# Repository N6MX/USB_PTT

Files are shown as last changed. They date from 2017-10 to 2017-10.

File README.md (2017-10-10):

#======================================================================================
#======================================================================================
# USB_PTT
# This is the design for a USB Push-To-Talk interface for amateur radio.
# This design was intended with work with the Yaesu FT-8900R, but will also work on radios with a similar interface.
#
# Author: Dylon Mutz, KK6OTK
# Email : dylon.mutz@gmail.com
#
# 10/7/2017 -- Initial release
#======================================================================================
#======================================================================================

99-usb_ptt.rules
   A udev rule is needed to set the device file to the dialout group with read/write permissions.
   Add this rules file to /etc/udev/rules.d/

ptt_driver/ptt_driver.ko
   This is the Linux kernel module (or driver) that is compiled from ptt_driver.c. This is the system-level middleman between the userspace application and the actual USB device hardware.
   The module can be loaded manually running the command "insmod <path to ptt_driver.ko"
   To allow the module to load automatically when the system is booted, follow the next steps:
      1) Make a new module directory in the kernel module folder
            "mkdir /lib/modules/`uname -r`/kernel/driver/ptt_driver"
      2) Allow the modprobe command to find the module by placing it under the "/lib/modules/`uname -r`" directory
            "cp usb_ptt/ptt_driver.ko /lib/modules/`uname -r`/kernel/driver/ptt_driver/"
      3) Regenerate module dependencies
            "depmod -ae
      4) Allow module to automatically load by placing a module config file in the "/etc/modules-load.d" directory
            "cp ptt_driver.conf /etc/modules-load.d/"

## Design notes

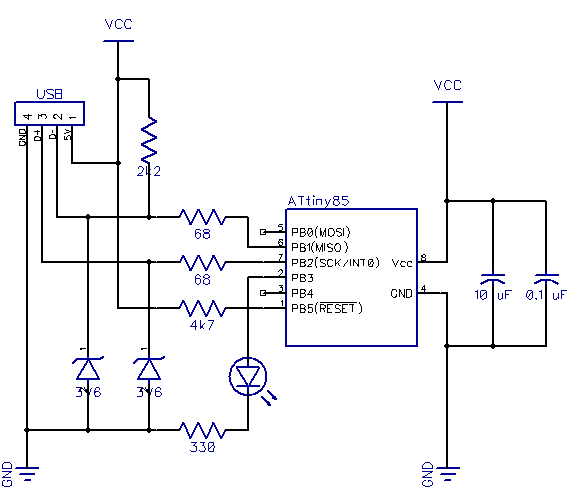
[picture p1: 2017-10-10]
usb_tiny85/schematic.png

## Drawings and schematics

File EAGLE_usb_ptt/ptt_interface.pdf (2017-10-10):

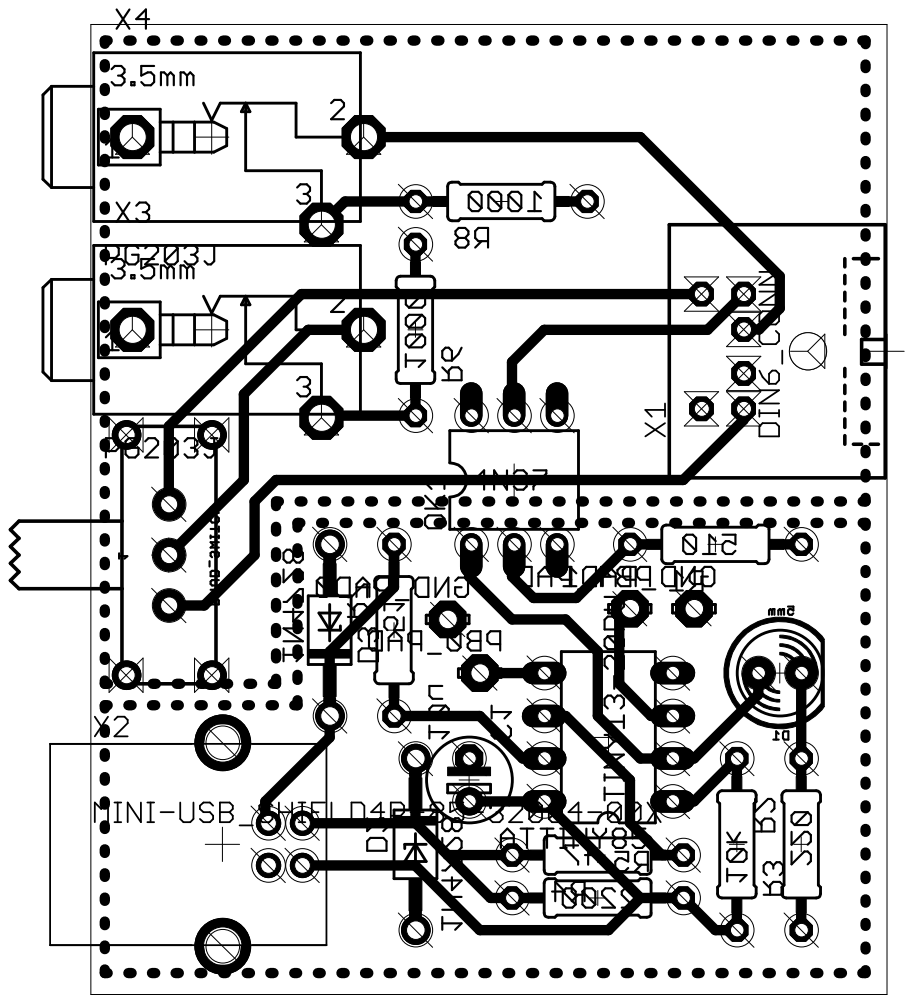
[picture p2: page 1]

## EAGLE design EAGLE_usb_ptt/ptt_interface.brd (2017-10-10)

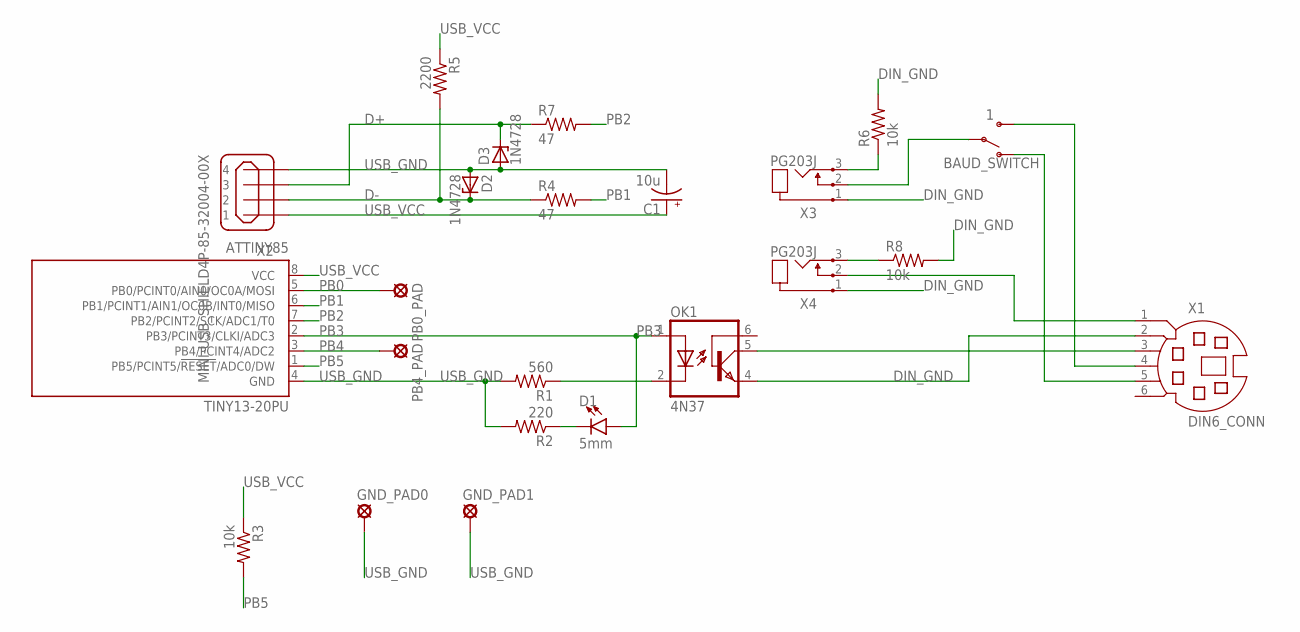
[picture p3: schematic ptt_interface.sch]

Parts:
ATTINY85: TINY13-20PU; DIL08
BAUD_SWITCH: 1; SWITCH_SPDT_PTH_15X5.6MM
C1: 10u; E2,5-5
D1: 5mm; LED_5MM
D2, D3: 1N4728; DO41Z10
GND_PAD0, GND_PAD1: LSP11
OK1: 4N37; DIL06
PB0_PAD, PB4_PAD: LSP11
R1: 560; 0207/10
R2: 220; 0207/10
R3, R6, R8: 10k; 0207/10
R4, R7: 47; 0207/10
R5: 2200; 0207/10
X1: DIN6_CONN; MDIN06SS
X2: MINI-USB_SHIELD4P-85-32004-00X; 85-32004-00X
X3, X4: PG203J

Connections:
D+: D3.C, R7.1, X2.3
D-: D2.C, R4.1, R5.2, X2.2
DIN_GND: OK1.4 (EMI), R6.2, R8.2, X1.2, X3.1, X4.1
unnamed: OK1.2 (C), R1.1
unnamed: D1.K (C), R2.1
unnamed: OK1.5 (COL), X1.3
unnamed: BAUD_SWITCH.2, X3.2 (3)
unnamed: R6.1, X3.3 (2)
unnamed: R8.1, X4.3 (2)
unnamed: BAUD_SWITCH.3 (S), X1.4
unnamed: BAUD_SWITCH.1 (O), X1.5
unnamed: X1.1, X4.2 (3)
PB0: ATTINY85.5 (PB0/PCINT0/AIN0/OC0A/MOSI), PB0_PAD.MP
PB1: ATTINY85.6 (PB1/PCINT1/AIN1/OC0B/INT0/MISO), R4.2
PB2: ATTINY85.7 (PB2/PCINT2/SCK/ADC1/T0), R7.2
PB3: ATTINY85.2 (PB3/PCINT3/CLKI/ADC3), D1.A, OK1.1 (A)
PB4: ATTINY85.3 (PB4/PCINT4/ADC2), PB4_PAD.MP
PB5: ATTINY85.1 (PB5/PCINT5/!RESET!/ADC0/DW), R3.2
USB_GND: ATTINY85.4 (GND), C1.-, D2.A, D3.A, GND_PAD0.MP, GND_PAD1.MP, R1.2, R2.2, X2.4
USB_VCC: ATTINY85.8 (VCC), C1.+, R3.1, R5.1, X2.1

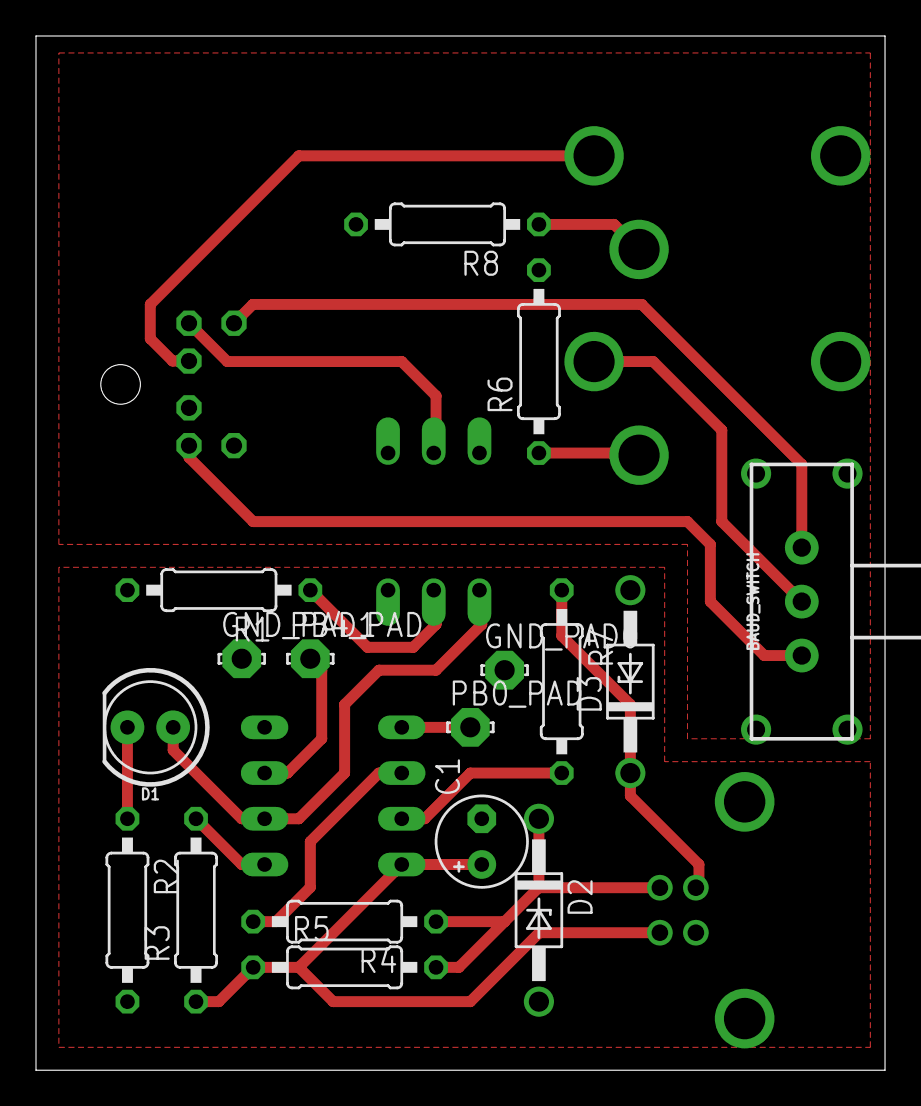
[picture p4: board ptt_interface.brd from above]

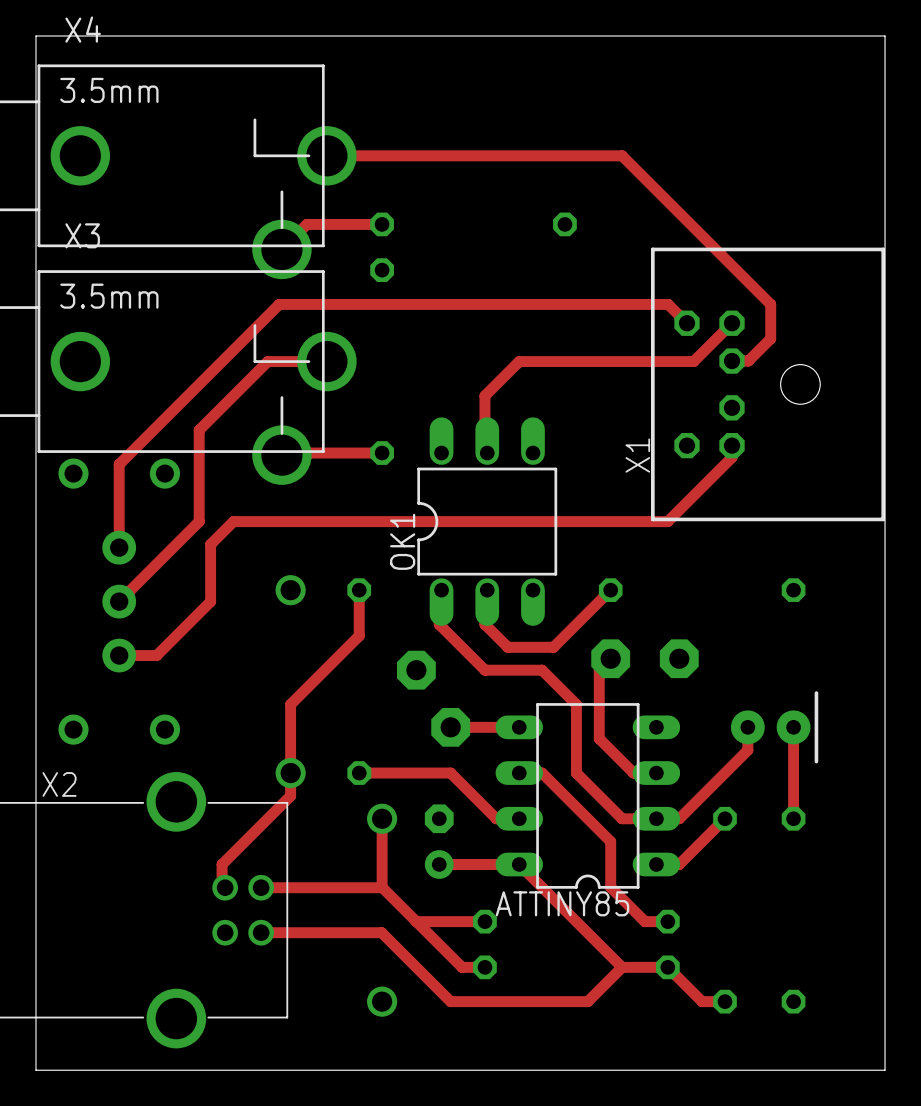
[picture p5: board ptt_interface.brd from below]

Board: 2 copper layers, 47.2 x 57.5 mm, 23 parts (6 on the bottom side), 20 nets.

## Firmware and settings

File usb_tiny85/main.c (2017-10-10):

/**
 * Project: AVR ATtiny USB Tutorial at http://codeandlife.com/
 * Author: Joonas Pihlajamaa, joonas.pihlajamaa@iki.fi
 * Inspired by V-USB example code by Christian Starkjohann
 * Copyright: (C) 2012 by Joonas Pihlajamaa
 * License: GNU GPL v3 (see License.txt)
 */
#include <avr/io.h>
#include <avr/interrupt.h>
#include <avr/wdt.h>
#include <util/delay.h>

#include "usbdrv.h"

//Function declarations
USB_PUBLIC uchar usbFunctionSetup(uchar data[8]);
void hadUsbReset();

#define USB_LED_OFF 0x00
#define USB_LED_ON 0x01
#define LED_PIN (1<<PB3)

//Main program
int main() {
	uchar i;

	DDRB = LED_PIN;					//Setup LED pin as output
	
    wdt_enable(WDTO_1S);			//Enable 1s watchdog timer

    usbInit();						//Initialize V-USB library

	//Enforce re-enumeration
	//Watchdog automatically resets chip after 1 second if freeze occurs
    usbDeviceDisconnect();
    for(i = 0; i<250; i++) {		//Wait 500 ms
        wdt_reset();				//Keep the watchdog happy
        _delay_ms(2);
    }
    usbDeviceConnect();
	
    sei();							//Enable interrupts after re-enumeration
	
    while(1) {
        wdt_reset();				//Keep the watchdog happy
        usbPoll();
    }
	
    return 0;
}


/************************************************************
********************SUPPORTING FUNCTIONS*********************
************************************************************/

// this gets called when custom control message is received
USB_PUBLIC uchar usbFunctionSetup(uchar data[8]) {
	usbRequest_t *rq = (void *)data; // cast data to correct type
	
	switch(rq->bRequest) { // custom command is in the bRequest field
    case USB_LED_ON:
		PORTB |= LED_PIN; // turn LED on
		return 0;
	case USB_LED_OFF: 
		PORTB &= ~LED_PIN; // turn LED off
		return 0;
    }

    return 1; // should not get here
}

#define abs(x) ((x) > 0 ? (x) : (-x))

// Called by V-USB after device reset
void hadUsbReset() {
    int frameLength, targetLength = (unsigned)(1499 * (double)F_CPU / 10.5e6 + 0.5);
    int bestDeviation = 9999;
    uchar trialCal, bestCal, step, region = 0;
    bestCal = 0;

    // do a binary search in regions 0-127 and 128-255 to get optimum OSCCAL
    for(region = 0; region <= 1; region++) {
        frameLength = 0;
        trialCal = (region == 0) ? 0 : 128;
        
        for(step = 64; step > 0; step >>= 1) { 
            if(frameLength < targetLength) // true for initial iteration
                trialCal += step; // frequency too low
            else
                trialCal -= step; // frequency too high
                
            OSCCAL = trialCal;
            frameLength = usbMeasureFrameLength();
            
            if(abs(frameLength-targetLength) < bestDeviation) {
                bestCal = trialCal; // new optimum found
                bestDeviation = abs(frameLength -targetLength);
            }
        }
    }

    OSCCAL = bestCal;
}

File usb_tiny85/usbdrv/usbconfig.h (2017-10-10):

/* Name: usbconfig.h
 * Project: V-USB, virtual USB port for Atmel's(r) AVR(r) microcontrollers
 * Author: Christian Starkjohann
 * Creation Date: 2005-04-01
 * Tabsize: 4
 * Copyright: (c) 2005 by OBJECTIVE DEVELOPMENT Software GmbH
 * License: GNU GPL v2 (see License.txt), GNU GPL v3 or proprietary (CommercialLicense.txt)
 * This Revision: $Id$
 */

#ifndef __usbconfig_h_included__
#define __usbconfig_h_included__

/*
General Description:
This file is an example configuration (with inline documentation) for the USB
driver. It configures V-USB for USB D+ connected to Port D bit 2 (which is
also hardware interrupt 0 on many devices) and USB D- to Port D bit 4. You may
wire the lines to any other port, as long as D+ is also wired to INT0 (or any
other hardware interrupt, as long as it is the highest level interrupt, see
section at the end of this file).
*/

/* ---------------------------- Hardware Config ---------------------------- */

#define USB_CFG_IOPORTNAME      B
/* This is the port where the USB bus is connected. When you configure it to
 * "B", the registers PORTB, PINB and DDRB will be used.
 */
#define USB_CFG_DMINUS_BIT      1
/* This is the bit number in USB_CFG_IOPORT where the USB D- line is connected.
 * This may be any bit in the port.
 */
#define USB_CFG_DPLUS_BIT       2
/* This is the bit number in USB_CFG_IOPORT where the USB D+ line is connected.
 * This may be any bit in the port. Please note that D+ must also be connected
 * to interrupt pin INT0! [You can also use other interrupts, see section
 * "Optional MCU Description" below, or you can connect D- to the interrupt, as
 * it is required if you use the USB_COUNT_SOF feature. If you use D- for the
 * interrupt, the USB interrupt will also be triggered at Start-Of-Frame
 * markers every millisecond.]
 */
#define USB_CFG_CLOCK_KHZ       (F_CPU/1000)
/* Clock rate of the AVR in kHz. Legal values are 12000, 12800, 15000, 16000,
 * 16500, 18000 and 20000. The 12.8 MHz and 16.5 MHz versions of the code
 * require no crystal, they tolerate +/- 1% deviation from the nominal
 * frequency. All other rates require a precision of 2000 ppm and thus a
 * crystal!
 * Since F_CPU should be defined to your actual clock rate anyway, you should
 * not need to modify this setting.
 */
#define USB_CFG_CHECK_CRC       0
/* Define this to 1 if you want that the driver checks integrity of incoming
 * data packets (CRC checks). CRC checks cost quite a bit of code size and are
 * currently only available for 18 MHz crystal clock. You must choose
 * USB_CFG_CLOCK_KHZ = 18000 if you enable this option.
 */

/* ----------------------- Optional Hardware Config ------------------------ */

/* #define USB_CFG_PULLUP_IOPORTNAME   D */
/* If you connect the 1.5k pullup resistor from D- to a port pin instead of
 * V+, you can connect and disconnect the device from firmware by calling
 * the macros usbDeviceConnect() and usbDeviceDisconnect() (see usbdrv.h).
 * This constant defines the port on which the pullup resistor is connected.
 */
/* #define USB_CFG_PULLUP_BIT          4 */
/* This constant defines the bit number in USB_CFG_PULLUP_IOPORT (defined
 * above) where the 1.5k pullup resistor is connected. See description
 * above for details.
 */

/* --------------------------- Functional Range ---------------------------- */
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

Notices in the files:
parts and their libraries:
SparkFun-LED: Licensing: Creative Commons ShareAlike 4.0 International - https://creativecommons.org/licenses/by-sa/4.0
